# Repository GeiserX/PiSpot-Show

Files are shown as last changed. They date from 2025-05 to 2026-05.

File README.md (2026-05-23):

> **⚠️ This project is archived.** Last active development was in 2018. The code is preserved here for reference purposes only and is no longer maintained.

<p align="center">PiSpot Show banner</p>

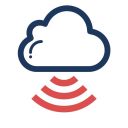
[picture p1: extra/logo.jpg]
PiSpot Show logo


<h1 align="center">PiSpot Show</h1>

<p align="center">
  <strong>Turn any HDMI display into a self-updating Wi-Fi voucher kiosk with live weather, powered by Raspberry Pi.</strong>
</p>

<p align="center">
  
  
  
  
  
</p>

---

## Overview

PiSpot Show is a headless Raspberry Pi appliance that drives hotel lobby TVs and public-area monitors. Every hour it generates a fresh time-limited Wi-Fi voucher from the [Spotipo](https://www.spotipo.com/) captive-portal API, pulls a live weather forecast, and composites everything into a branded Full-HD image rendered directly to the Linux framebuffer -- no desktop environment required.

A [PiJuice HAT](https://github.com/PiSupply/PiJuice) provides battery-backed power management with RTC wake/sleep scheduling, a hardware watchdog, and graceful low-voltage shutdown, making the device suitable for unattended 24/7 operation.

Originally developed and deployed in 2018 for the company GPConnect. Part of the **PiSpot ecosystem**:

| Project | Description |
|---|---|
| [PiSpot Watch](https://github.com/GeiserX/PiSpot-Watch) | Wrist-wearable e-ink voucher device |
| **PiSpot Show** (this repo) | HDMI kiosk display for lobby TVs |
| [PiSpot Deployment](https://github.com/GeiserX/PiSpot-Deployment) | Fleet provisioning and Vault configuration |

---

## Features

- **Hourly voucher rotation** -- generates a new Spotipo Wi-Fi voucher every hour with configurable duration, speed limits, device caps, and data quotas.
- **Live weather overlay** -- fetches temperature, "feels like", daily min/max, conditions, and forecast summary from the Dark Sky API with matching weather icons.
- **Full-HD branded output** -- 1920x1080 image composited with Pillow using custom Raleway typography, logos, SSID, voucher code, weather data, and current date.
- **Framebuffer rendering** -- pushes images directly to `/dev/fb0` via `fbi`, bypassing X11/Wayland entirely for a minimal, kiosk-grade display pipeline.
- **PiJuice power management** -- battery UPS with RTC wake-up alarms (e.g. 09:00 weekdays), scheduled shutdown via cron, hardware watchdog (5s), wake-on-charge at 20%.
- **Boot splash screen** -- displays branding immediately on power-on via a dedicated systemd unit, before the main service starts.
- **Ansible deployment** -- single playbook provisions packages, creates users, generates SSH keys, clones the repo, registers services, configures WiFi, and optimizes GPU/USB power.
- **3D-printable enclosure** -- FreeCAD parametric designs and ready-to-print STLs for a custom case with button panel and lid.
- **Error resilience** -- on API failure, renders an error screen and retries after 60 seconds without crashing.

---

## Videos

### In Action

PiSpot Show In Action (http://www.youtube.com/watch?v=Uocjf3nof9g "PiSpot Show In Action")

### Assembly

PiSpot Show Assembly (http://www.youtube.com/watch?v=0NGtbnZm6PA "PiSpot Show Assembly")

---

## Photos

<p align="center">
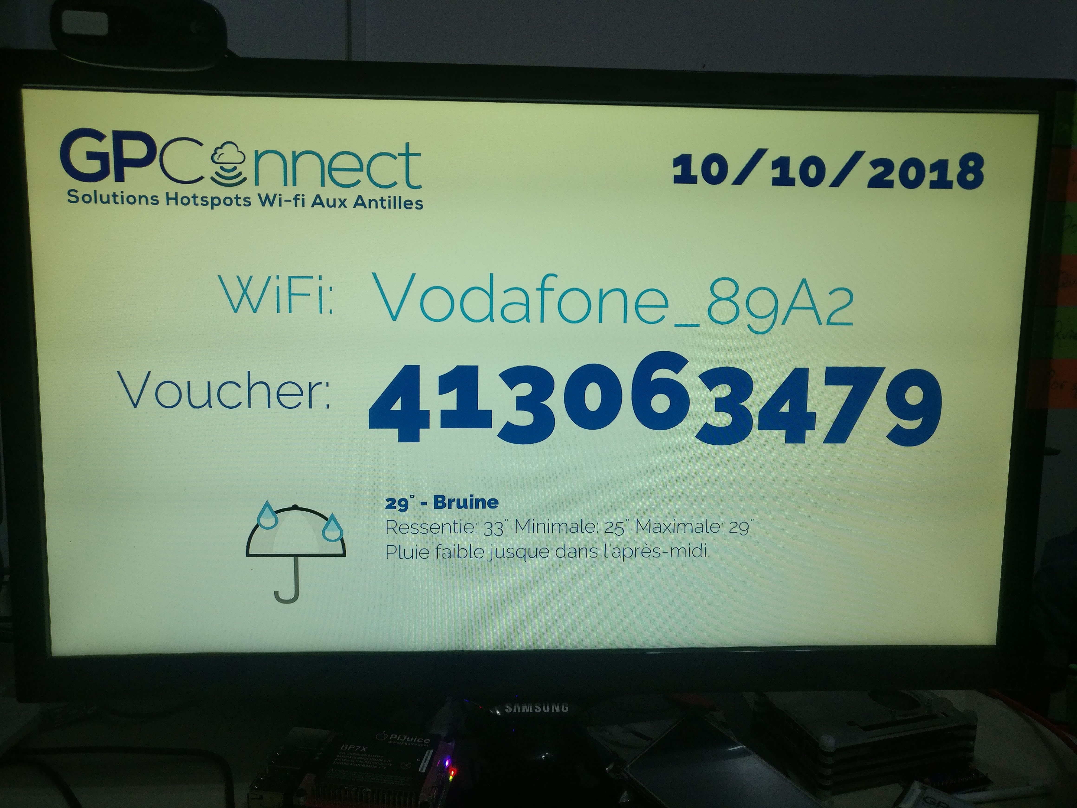
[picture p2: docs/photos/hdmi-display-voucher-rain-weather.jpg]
HDMI display showing voucher with rain weather
  
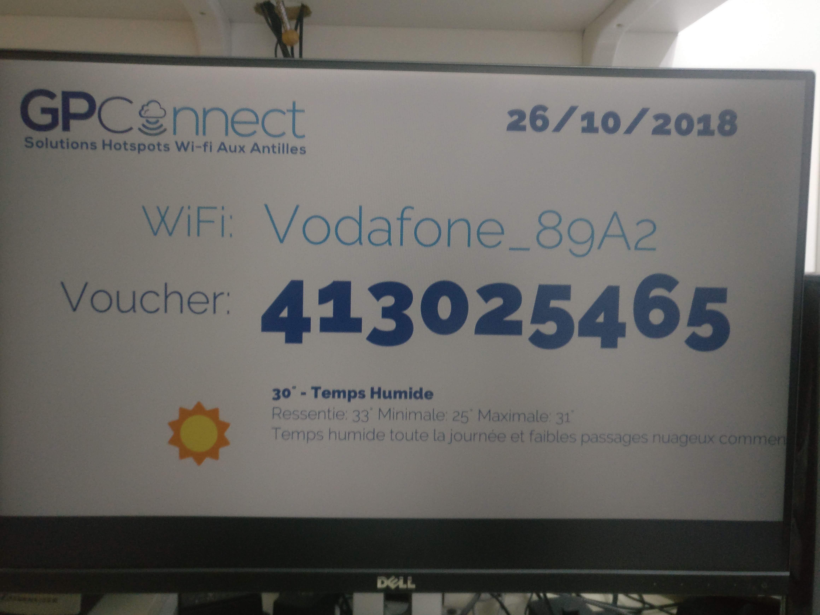
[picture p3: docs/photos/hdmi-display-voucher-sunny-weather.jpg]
HDMI display showing voucher with sunny weather
  
</p>
<p align="center">
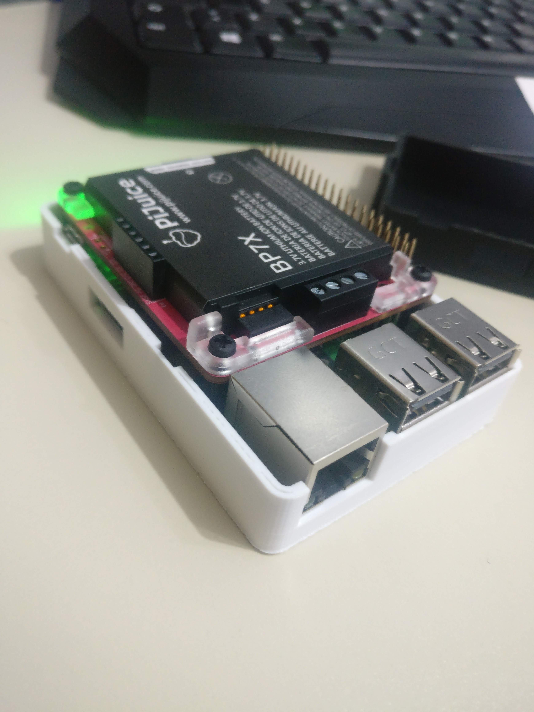
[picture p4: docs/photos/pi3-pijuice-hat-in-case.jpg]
Raspberry Pi 3 with PiJuice HAT
  
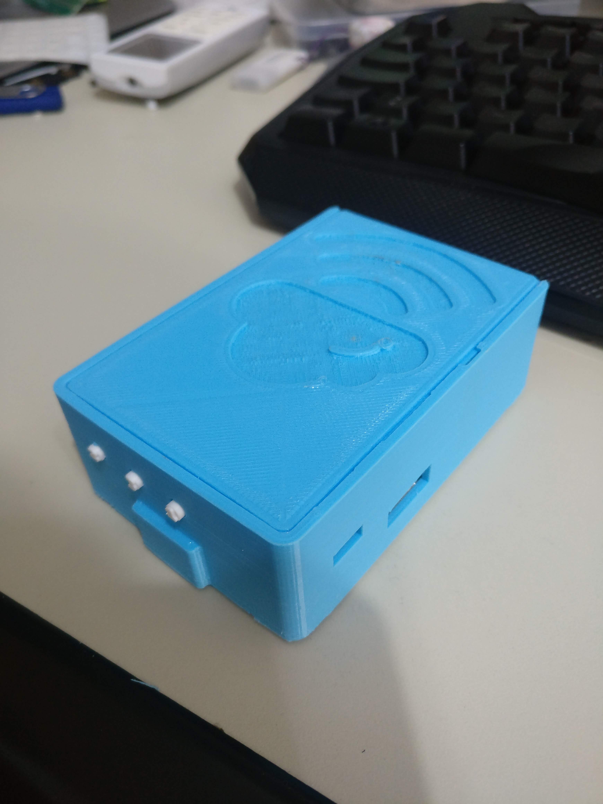
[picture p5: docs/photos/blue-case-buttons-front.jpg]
Blue 3D-printed case with buttons
  
</p>
<p align="center">
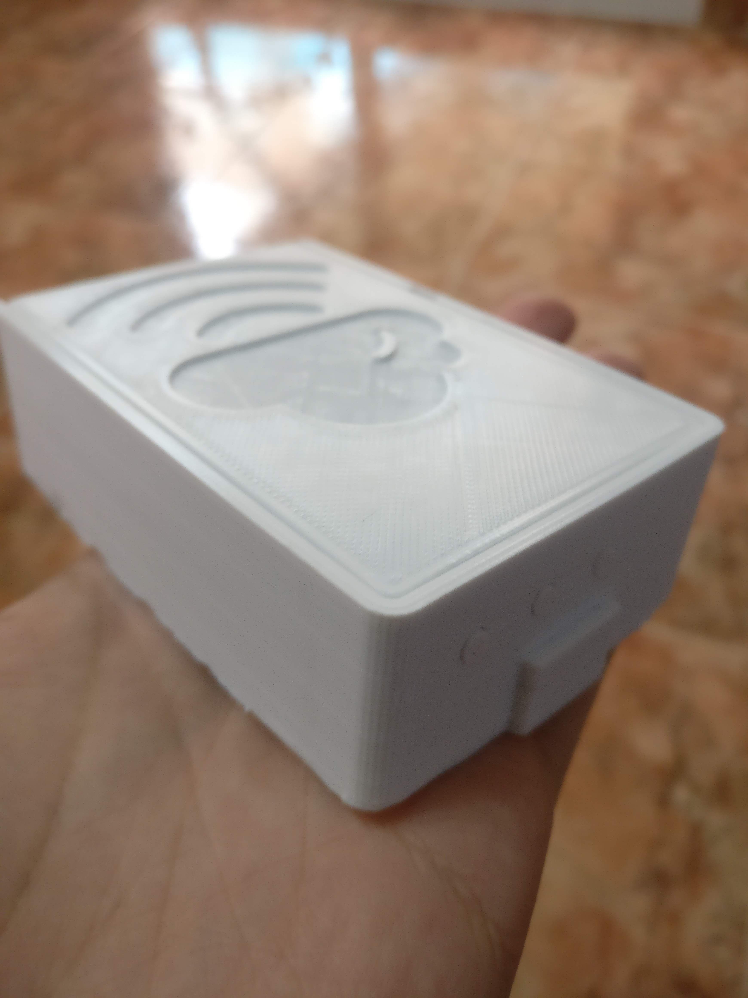
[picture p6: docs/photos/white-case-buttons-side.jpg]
White case with buttons
  
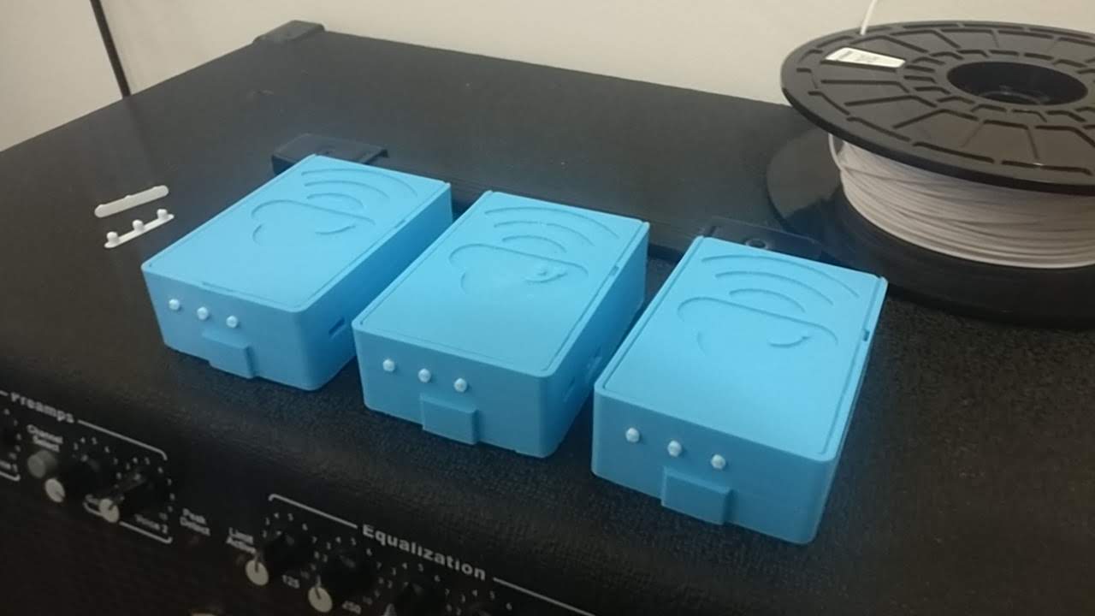
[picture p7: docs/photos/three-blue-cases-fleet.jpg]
Fleet of three blue cases
  
</p>

See all photos in [`docs/photos/`](docs/photos/).

---

## Architecture

```
                         +------------------+
                         |   HDMI Display   |
                         |   (1920x1080)    |
                         +--------+---------+
                                  |
                         +--------+---------+
                         |   Raspberry Pi   |
                         |   + PiJuice HAT  |
                         +--+-----+------+--+
                            |     |      |
                  +---------+  +--+--+  ++----------+
                  |            |     |  |            |
          +-------v---+ +-----v-+ +-v--v------+ +---v--------+
          | Spotipo   | | Dark  | | Pillow    | | fbi        |
          | WiFi API  | | Sky   | | (image    | | (framebuf  |
          | (voucher) | | (wx)  | |  render)  | |  display)  |
          +-----------+ +-------+ +-----------+ +------------+
```

1. **main.py** runs in an infinite loop as a systemd service.
2. Each hour, it POSTs to the Spotipo API to create a time-limited voucher.
3. It GETs the current weather from Dark Sky (with localized language support).
4. Pillow composites the voucher code, SSID, weather data, date, and branding onto a 1920x1080 PNG.
5. `fbi` pushes the image to the Linux framebuffer.
6. **piJuice_stop.py** is called via cron to trigger a timed shutdown; the PiJuice RTC alarm handles the next wake-up.

---

## Hardware

| Component | Purpose |
|---|---|
| Raspberry Pi 3 (or later) | Main compute board |
| PiJuice HAT (1680 mAh) | Battery UPS, RTC alarms, watchdog, wake-on-charge |
| HDMI display (TV or monitor) | Guest-facing 1920x1080 voucher screen |
| MicroSD card (8 GB+) | Raspbian OS + application |
| Power supply (5 V / 2.5 A) | Board + HAT power |

---

## Getting Started

### 1. Clone

```bash
git clone https://github.com/GeiserX/PiSpot-Show.git
cd PiSpot-Show
```

### 2. Configure API keys

Edit `main.py` and set your credentials:

```python
Spotipo_Key  = "YOUR-SPOTIPO-TOKEN"
Darksky_Key  = "YOUR-DARKSKY-KEY"
```

Also update the Spotipo endpoint URL, SSID name, and weather coordinates.

### 3. Deploy with Ansible

```bash
ansible-playbook -i inventory deployment-files/main.yml
```

The playbook handles: system packages (`fbi`, `pijuice-base`, `imagemagick`), Python dependencies, dedicated user with scoped sudo, SSH key generation, service registration, WiFi, timezone, and GPU/USB power optimization.

### 4. Configure PiJuice schedule

Set the RTC wake alarm via `pijuice_cli` (e.g. 09:00 weekdays) and add the shutdown cron:

```bash
crontab -e
# 0 17 * * * /usr/bin/python3 /opt/PiSpot_HDMI/piJuice_stop.py
```

---

## Configuration

### Voucher parameters

Set in the API request body inside `main.py`:

| Parameter | Default | Description |
|---|---|---|
| `duration_val` | `4` | Voucher validity period |
| `duration_type` | `2` | Duration unit (1=min, 2=hour, 3=day) |
| `num_devices` | `10` | Max concurrent devices per voucher |
| `speed_dl` | `1024` | Download speed limit (Kbps) |
| `speed_ul` | `256` | Upload speed limit (Kbps) |
| `bytes_t` | `0` | Data cap (0 = unlimited) |

### PiJuice events

Defined in `pijuice_config.JSON`:

- **Low battery** -- halt and power off
- **Watchdog reset** -- automatic reboot (5s period)
- **Wake-on-charge** -- boot at 20% battery
- **Button / forced power off** -- graceful halt

---

## 3D-Printable Enclosure

The `Case/` directory contains a complete enclosure designed in FreeCAD:

| File | Description |
|---|---|
| `Caja.stl` | Main housing body |
| `Tapa.stl` | Top lid / cover |
| `Botonera.stl` | Button panel insert |
| `*.fcstd` | FreeCAD parametric source files |
| `*.gx` | Goxel voxel models |

---

## Project Structure

```
PiSpot-Show/
  main.py                    # Main loop: voucher + weather + render + display
  piJuice_stop.py            # Scheduled shutdown script
  pijuice_config.JSON        # PiJuice HAT event/watchdog configuration
  fonts/                     # Raleway Light + Black typeface
  images/                    # Backgrounds, logos, weather icons, generated output
  servicefiles/
    pispot_hdmi.service      # Main application systemd unit
    splashscreen.service     # Boot splash systemd unit
  deployment-files/
    main.yml                 # Ansible provisioning playbook
    wpa_supplicant.conf      # WiFi network configuration
    GitLabANDHostname.py     # SSH key + hostname setup for fleet devices
  Case/                      # 3D enclosure (FreeCAD + Goxel + STL)
  LICENSE                    # GPL-3.0
```

---

## License

[GNU General Public License v3.0](LICENSE)

## Maintainers

[@GeiserX](https://github.com/GeiserX)

## Contributing

Contributions are welcome. [Open an issue](https://github.com/GeiserX/PiSpot-Show/issues/new) or submit a pull request.

This project follows the [Contributor Covenant v2.1](https://www.contributor-covenant.org/version/2/1/code_of_conduct/) Code of Conduct.

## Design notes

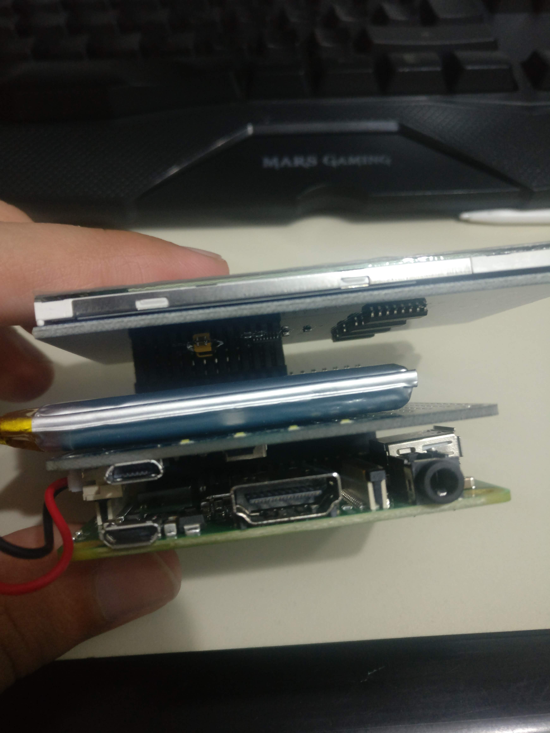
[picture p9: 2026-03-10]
docs/photos/prototype-ups-hat-tft-angle.jpg

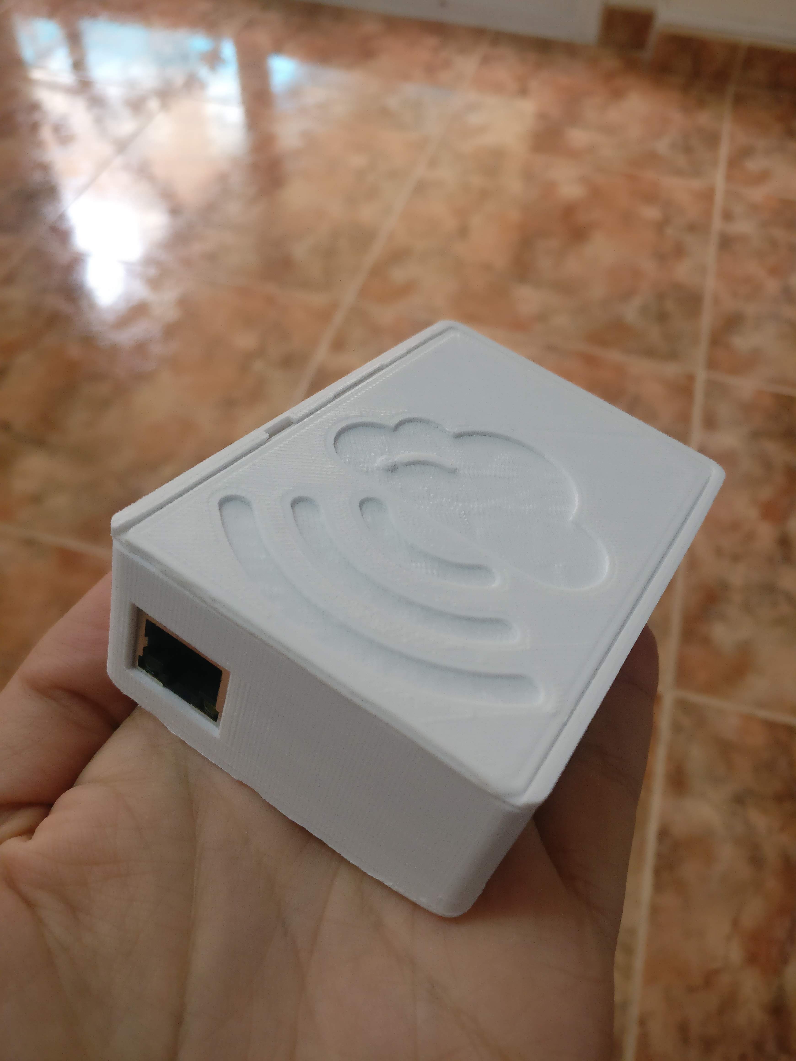
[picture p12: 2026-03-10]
docs/photos/white-case-ethernet-side.jpg

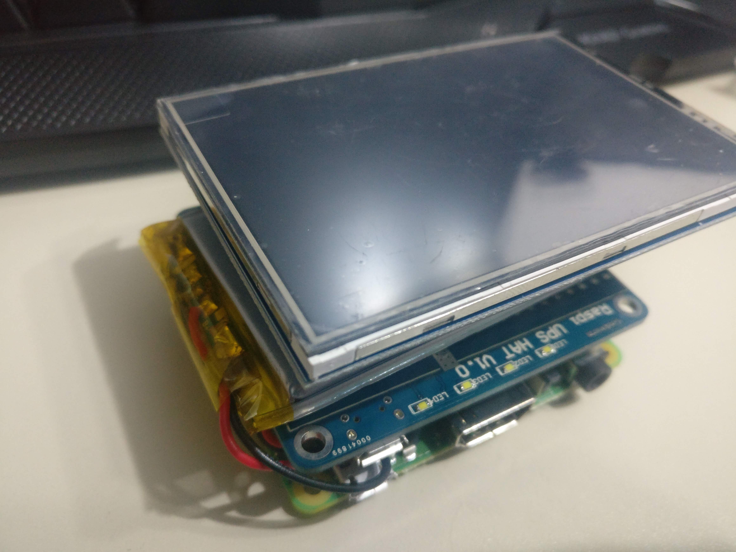
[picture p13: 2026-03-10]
docs/photos/prototype-ups-hat-tft-side.jpg

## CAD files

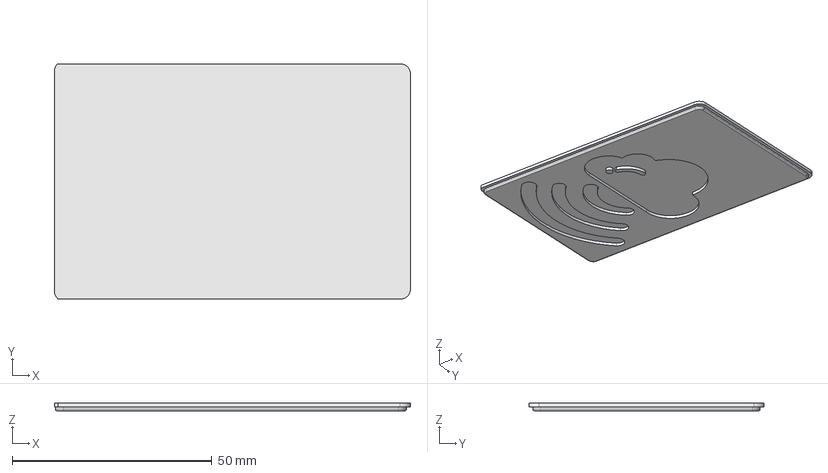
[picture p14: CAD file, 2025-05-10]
Case/Final despues de cortar.fcstd
89.2 x 59.0 x 2.00 mm

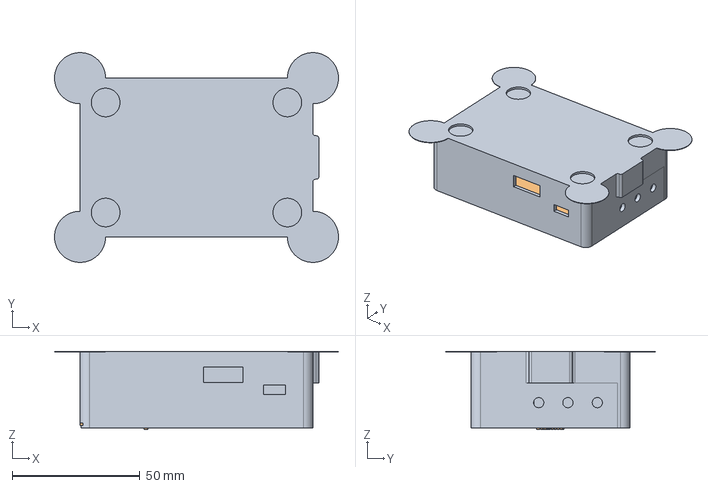
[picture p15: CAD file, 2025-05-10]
Case/Final antes de cortar.fcstd
111.0 x 82.0 x 30.5 mm
Caja
Tapa

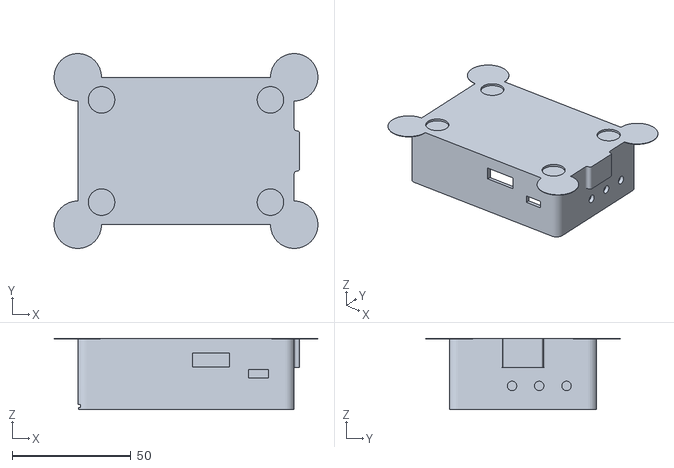
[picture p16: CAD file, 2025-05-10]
Case/Caja.stl
111.0 x 82.0 x 30.0

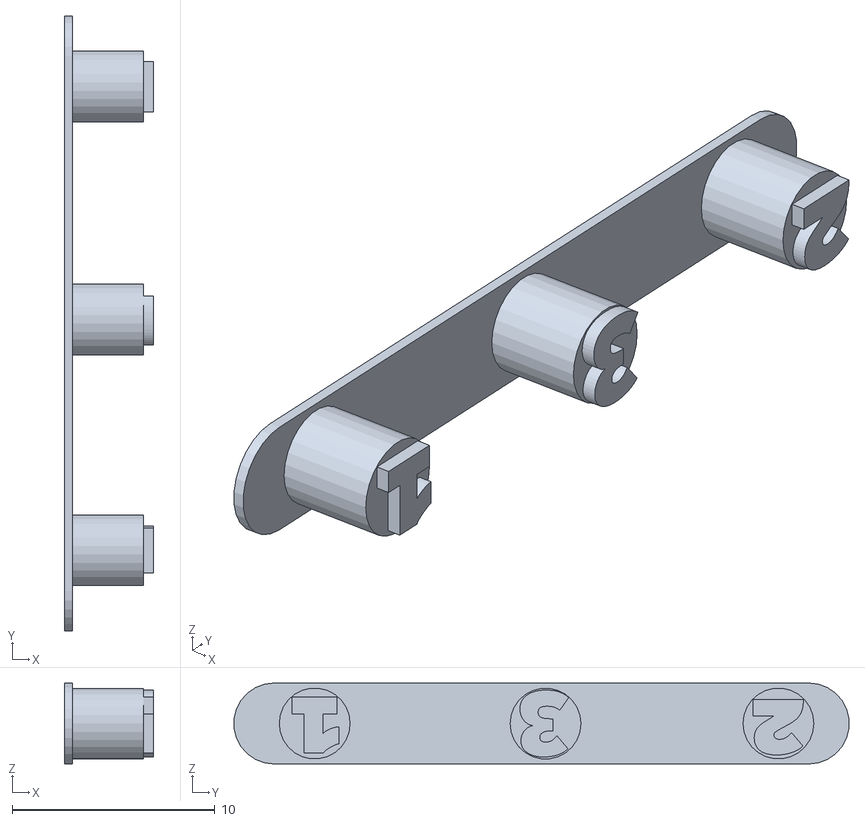
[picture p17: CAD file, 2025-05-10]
Case/Botonera.stl
4.40 x 30.4 x 4.00

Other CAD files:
Case/Tapa.stl

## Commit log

2025-05-10 First commit - 2018
    [Botonera.stl, Caja.stl, Final antes de cortar.fcstd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]
2026-03-10 Add 15 project photos and video links
    Photos categorized from original development (2018-2019):
    HDMI display outputs with weather, Pi 3 + PiJuice internals,
    3D-printed cases in blue and white variants, fleet production.
    Added assembly and in-action YouTube video links to README.
2026-03-10 Add 3 UPS HAT prototype photos
    Experimental build with Geekworm Raspi UPS HAT v1.0,
    TFT LCD display, and LiPo battery on Pi Zero.
2026-03-10 Remove misplaced Watch photo from Show repo
    white-case-ports-side.jpg was a Pi Zero + e-ink + battery
    photo, moved to PiSpot-Watch.
